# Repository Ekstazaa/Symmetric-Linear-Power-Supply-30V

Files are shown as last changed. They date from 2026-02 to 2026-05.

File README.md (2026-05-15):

# 🔌 Symetryczny zasilacz liniowy ±30 V

Projekt liniowego zasilacza symetrycznego przeznaczonego do zastosowań laboratoryjnych oraz testowania układów analogowych.

Układ umożliwia regulację napięcia dodatniego i ujemnego względem wspólnej masy oraz został zaprojektowany i zbudowany od podstaw – od schematu, przez PCB, aż po kompletną obudowę.

---

## 📷 Zdjęcia

### 🔧 Wnętrze


### 🎛️ Panel przedni


### 🔌 Tył


---

## ⚙️ Specyfikacja
\
| Parametr | Wartość |
|---|---|
| Napięcie wyjściowe | ±1.5 V do ±24 V (testowane) |
| Maksymalny prąd z jednej linii | ~1.5 A (regulatory) / ~4.5 A (z tranzystorami) |
| Transformator | toroidalny |
| Prąd transformatora | ~1.25 A |
| Topologia | liniowa |

---

## 🧠 Architektura

### Główne elementy:
- transformator toroidalny  
- mostek prostowniczy  
- kondensatory filtrujące  
- regulatory LM317 / LM337  
- tranzystory mocy (zwiększenie wydajności prądowej)  

---

## 🔌 Wyjścia

- 🔴 czerwony — +V  
- 🟢 zielony — GND  
- ⚫ czarny — -V  

---

## 🧪 Testy

Zasilacz został przetestowany przy użyciu prostych obciążeń (LED + rezystor).

Obserwacje:
- poprawna regulacja napięcia w całym zakresie  
- stabilna praca  
- brak zauważalnych problemów z regulacją  

---

## ⚠️ Problemy i kompromisy projektowe

### Inrush current

Największym problemem projektu okazał się prąd rozruchowy.

Duże kondensatory filtrujące na wejściu powodują:
- bardzo duży impuls prądu przy starcie  
- przepalanie bezpiecznika 1 A w gnieździe zasilania  

Tymczasowe rozwiązanie:
- zastosowanie bezpiecznika 4.5 A  

Nie jest to rozwiązanie docelowe, ponieważ:
- przekracza nominalny prąd transformatora (~1.25 A)  
- zmniejsza skuteczność zabezpieczenia  

Planowane rozwiązania:
- przeniesienie kondensatorów redukujących tętnienia z przed regulatorami do wyjścia regulatorów, które mają już konstrukcje softstartu.

---

### Ograniczenie prądu

- regulatory LM317 / LM337 posiadają ograniczenie prądowe (~1.5 A)  
- tranzystory mocy nie są zabezpieczone  

Planowane ulepszenie:
- zworka / bezpiecznik w torze tranzystorów  
- łatwiejsze debugowanie i zabezpieczenie układu  

### Kondensatory X i Y

- brakuje kondensatorów bezpieczeństaw X i Y

---

### Pomiar napięcia

Zastosowane analogowe mierniki:
- nie rozróżniają napięcia ujemnego  
- wskazują wartość bez uwzględnienia znaku  

---

### Mechanika i chłodzenie

- obudowa jest dość ciasna  
- ograniczony przepływ powietrza  
- potencjalne problemy termiczne przy dużym obciążeniu  

---

## 💬 Podsumowanie

Projekt jest w pełni działający i spełnia swoje założenia, jednak wymaga dalszego dopracowania w zakresie:

- zarządzania prądem rozruchowym  
- zabezpieczeń  
- warunków termicznych

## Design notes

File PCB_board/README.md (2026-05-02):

# Regulowany symetryczny zasilacz liniowy (Dual-Rail)

https://github.com/Ekstazaa/Symmetric-Linear-Power-Supply-30V/blob/main/PCB_board/README.md

---

## 📖 Opis

Ta płytka PCB implementuje transformatorowy, regulowany, symetryczny zasilacz liniowy oparty na układach LM317 (szyna dodatnia) oraz LM337 (szyna ujemna).  

Projekt jest przeznaczony do zastosowań laboratoryjnych oraz audio, gdzie wymagane jest regulowane napięcie symetryczne.

Zasilacz zawiera tranzystory mocy zwiększające wydajność prądową, zabezpieczenia wyjścia, dodatkową gałąź zasilania dla elektroniki panelowej oraz standardowe elementy stabilizujące zgodne z notami katalogowymi regulatorów.

---

### 🧊 Model 3D:


### 📐 Schemat:


---

## ⚡ Stopień wejściowy

Zasilacz jest zasilany z transformatora o parametrach:

- 2 × 32 VAC  
- Maksymalny prąd: 5 A na uzwojenie  

Prostowanie realizowane jest w konfiguracji dwudiodowej (pełnookresowej).

Po prostowaniu:

Każda szyna zawiera dwa kondensatory filtrujące 4700 µF (łącznie 9.4 mF na szynę).  
Ze względu na umiarkowaną pojemność filtrującą oraz możliwość pracy przy większych obciążeniach, tętnienia napięcia rosną przy wysokim poborze prądu.

---

## 🔧 Stopień regulacji

Regulacja napięcia realizowana jest przy użyciu:

- LM317 (szyna dodatnia)  
- LM337 (szyna ujemna)  

Regulatory są sterowane za pomocą zewnętrznych potencjometrów wieloobrotowych (montowanych na panelu przednim).

Dodatkowo na PCB przewidziano footprinty THT dla potencjometrów, co pozwala:
- używać regulacji bezpośrednio na płytce  
- skonfigurować układ jako źródło napięcia stałego  



Każdy regulator zawiera:

- kondensator wejściowy 100 nF  
- kondensator wyjściowy 1 µF  
- diody zabezpieczające przed rozładowaniem wstecznym  
- układ biasu startowego (kontrola zachowania przy starcie)

---

## 🔋 Stopień zwiększenia prądu

Aby zwiększyć wydajność prądową ponad ograniczenie ~1.5 A regulatorów LM317/LM337, zastosowano po jednym tranzystorze mocy (serii TIP) na każdą szynę.

Pozwala to na uzyskanie większego prądu wyjściowego, przy zachowaniu stabilizacji przez regulatory.

Zabezpieczenia wyjścia:

- bezpiecznik 4 A na każdą szynę  

Projekt zakłada maksymalny prąd ciągły na poziomie około 4 A.

---

## 📈 Maksymalne napięcie wyjściowe

Mimo zastosowania transformatora 2 × 30 VAC, maksymalne stabilizowane napięcie wyjściowe wynosi około:

±28 V DC  

Ograniczenie wynika ze spadków napięcia na:

- diodach prostownika  
- rezystancjach pasożytniczych  
- napięciu dropout regulatorów  
- spadku V_BE tranzystorów TIP  

---

## 🌡️ Warunki termiczne

Ze względu na wysokie napięcie wejściowe, przy niskim napięciu wyjściowym wydzielana jest znaczna moc strat.

Przybliżenie:

P ≈ (Vin - Vout) × Iout  

Ciepło wydziela się głównie w:

- regulatorach LM317 / LM337  
- tranzystorach mocy  

Zastosowane radiatory pozwalają na:

- LM317 / LM337: ~10 W  
- tranzystory TIP: ~17 W  

Zakłada to odpowiedni przepływ powietrza i poprawny montaż mechaniczny.  
Przy dużym prądzie i niskim napięciu wyjściowym może być wymagane dodatkowe chłodzenie.

---

## 🔌 Zasilanie pomocnicze

Dodatkowa gałąź oparta o LM7818 zapewnia:

- zasilanie mierników panelowych  
- diodę sygnalizacyjną LED  



---

## ⚠️ Uwagi projektowe i ograniczenia

Projekt został wykonany z użyciem transformatora 2 × 30 V, głównie ze względu na jego dostępność.  

W praktyce bardziej optymalny byłby transformator o niższym napięciu wtórnym (np. 2 × 16–18 V).

W obecnym zastosowaniu wymagane napięcie to maksymalnie ±12 V, co oznacza, że:

- transformator jest przewymiarowany napięciowo  
- występują duże spadki napięcia na regulatorach  
- generowane są znaczne straty mocy  

W przyszłości planowana jest zmiana transformatora na lepiej dopasowany do zastosowania.  
Obecnie testy wykonywane są bez dużych obciążeń.

Dodatkowo:

- PCB umożliwia montaż potencjometrów THT  
- dostępne są dwa terminale śrubowe na każdą szynę (większa wygoda i elastyczność)

---

## 📁 Opis plików projektu

- **Power_supply.kicad_sch**  
  Schemat elektryczny w KiCad

- **Power_supply.kicad_pcb**  
  Layout PCB (rozmieszczenie elementów i ścieżki)

- **Power_supply.kicad_pro**  
  Plik projektu KiCad

- **Power_supply.zip**  
  Pliki produkcyjne (Gerbery + wiercenia)

- **bom.csv**  
  Lista elementów (Bill of Materials)

- **positions.csv**  
  Plik pick-and-place (pozycje komponentów)

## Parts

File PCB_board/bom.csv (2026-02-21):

Designator | Footprint | Quantity | Value | LCSC Part #
C1, C2, C3, C4 | HE1J478M30040HA | 4 | 4m7
C10, C9 | C_Radial_D5.0mm_H7.0mm_P2.00mm | 2 | 10u
C11, C12, C5, C6 | 0805 | 4 | 100n
C7, C8 | 0805 | 2 | 1u
D1, D2, D3, D4, D5, D6 | D_DO-201AD_P15.24mm_Horizontal | 6 | 1N5408
D7, D8 | D_SOD-523 | 2 | 1N4148WT
H2, H3 | PTF15 | 2 | Fuse4A
IC1 | TO255P460X1020X2008-3P | 1 | LM317T
IC2 | TO255P460X1020X2008-3P | 1 | LM337SP
J1 | DG3015003P1200AH | 1 | DG301-5.0-03P-12-00A_H_
J2 | 2828366 | 1 | 282836-6
J3 | PinSocket_2x06_P2.54mm_Vertical | 1 | Conn_02x06_Counter_Clockwise
Q1 | TO545P515X1560X2445-3P | 1 | TIP2955
Q2 | TO545P515X1560X2445-3P | 1 | TIP3055
Q3 | SOT-23 | 1 | BC807
Q4 | SOT-23 | 1 | BC817
R1, R3 | 0603 | 2 | 240
R2, R4 | 0603 | 2 | 50k
R5, R8 | R_Axial_DIN0516_L15.5mm_D5.0mm_P20.32mm_Horizontal | 2 | 0.1
R6, R7 | R_Axial_DIN0516_L15.5mm_D5.0mm_P20.32mm_Horizontal | 2 | 1
R9 | 0603 | 1 | 2k
RV+1, RV-1 | Potentiometer_ACP_CA9-H5_Horizontal | 2 | R_Potentiometer
U1 | TO-220-3_Vertical | 1 | LM7818_TO220
U2, U3, U4, U5 | FAT22025E | 4 | FA-T220-25E

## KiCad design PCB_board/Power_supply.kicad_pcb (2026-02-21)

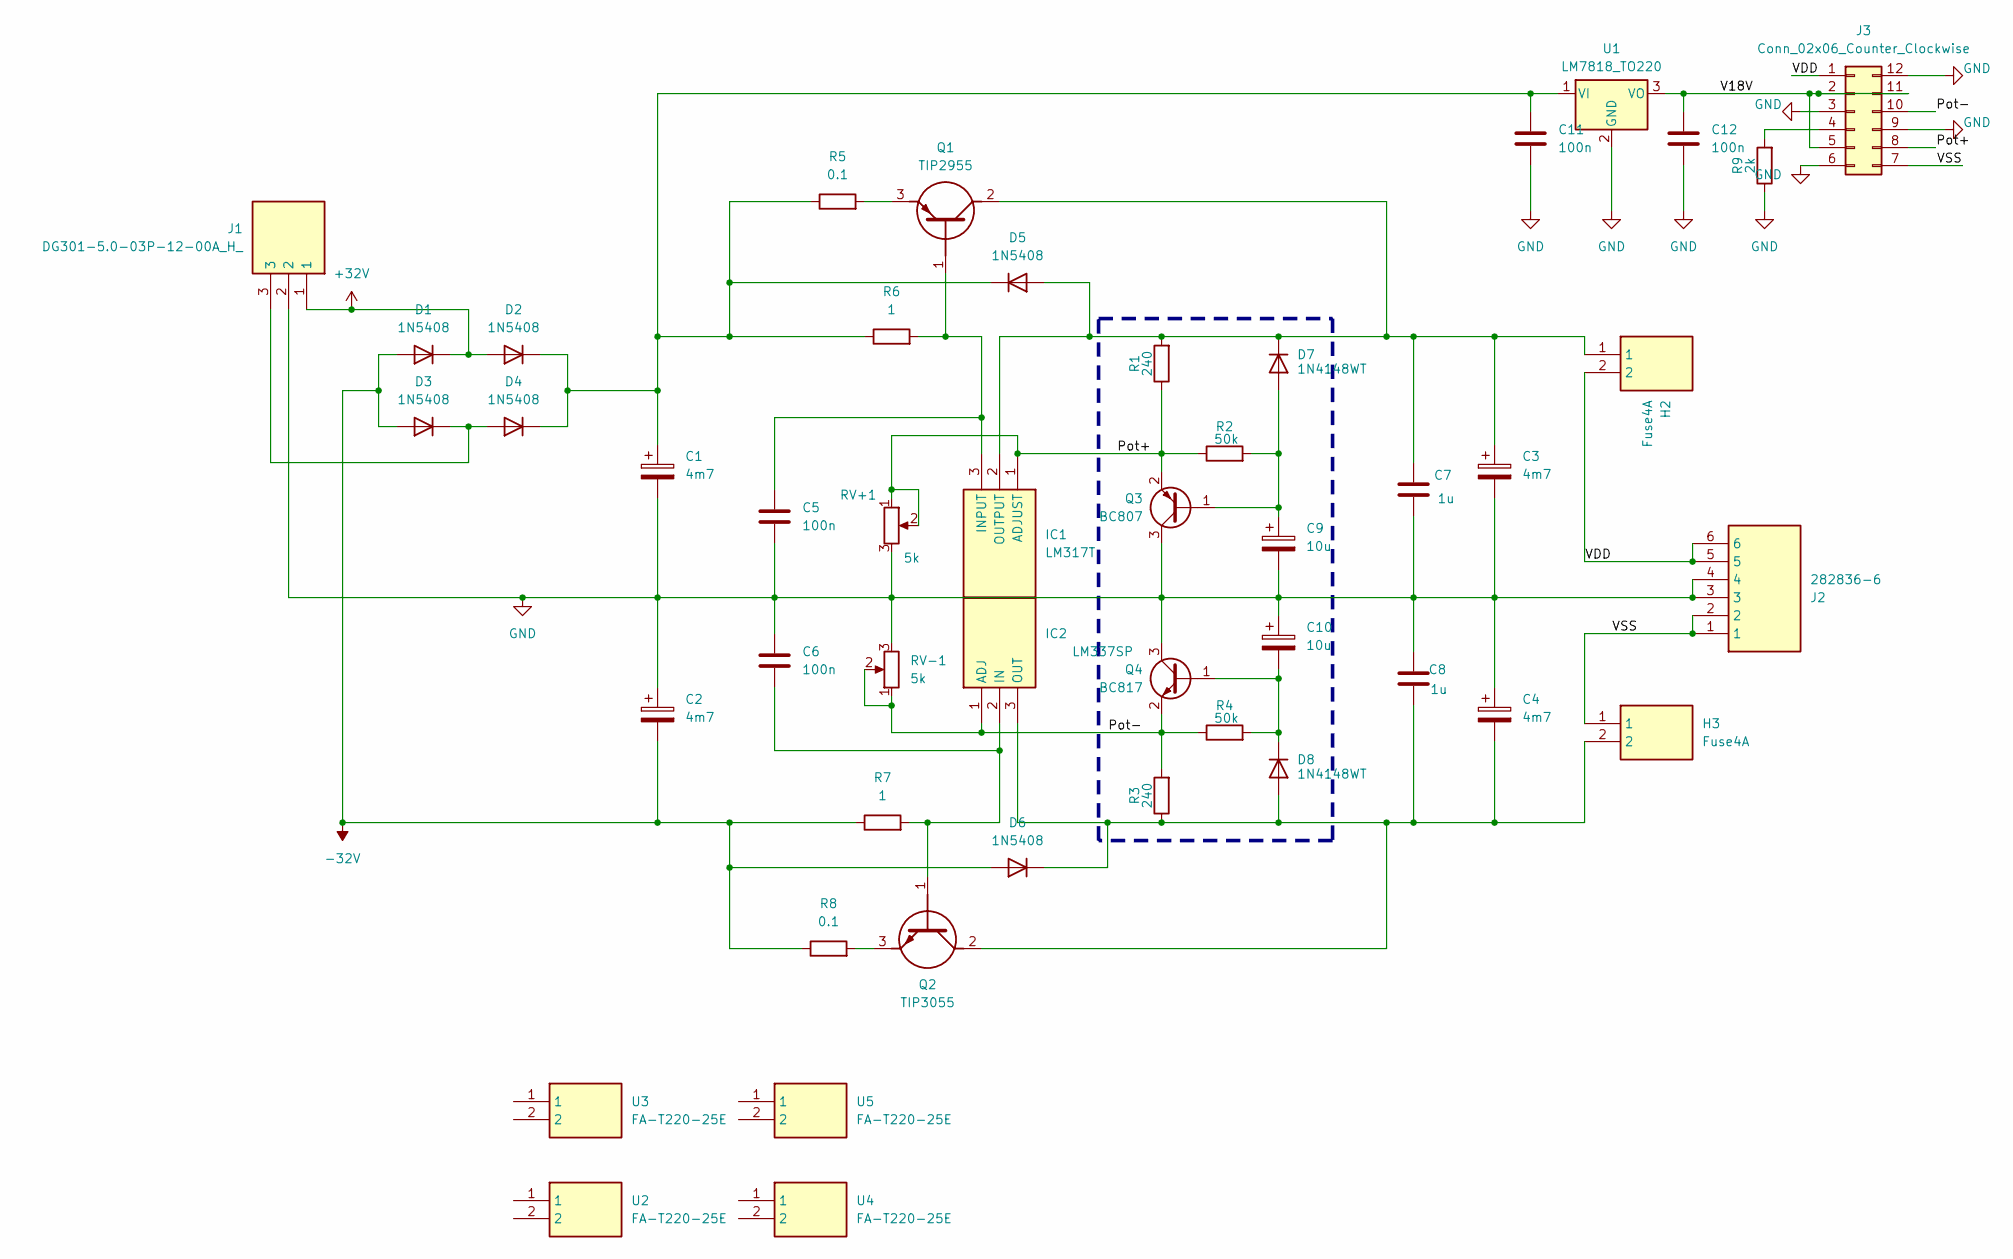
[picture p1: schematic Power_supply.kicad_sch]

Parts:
C1, C2, C3, C4: 4m7; HE1J478M30040HA
C5, C6, C11, C12: 100n; C_0805_2012Metric
C7, C8: 1u; C_0805_2012Metric
C9, C10: 10u; C_Radial_D5.0mm_H7.0mm_P2.00mm
D1, D2, D3, D4, D5, D6: 1N5408; D_DO-201AD_P15.24mm_Horizontal
D7, D8: 1N4148WT; D_SOD-523
H2, H3: Fuse4A; PTF15; Manufacturer_Part_Number PTF/15
IC1: LM317T; TO255P460X1020X2008-3P; Manufacturer_Part_Number LM317T
IC2: LM337SP; TO255P460X1020X2008-3P; Manufacturer_Part_Number LM337SP
J1: DG301-5.0-03P-12-00A_H_; DG3015003P1200AH; Manufacturer_Part_Number DG301-5.0-03P-12-00A(H)
J2: 282836-6; 2828366; Manufacturer_Part_Number 282836-6
J3: Conn_02x06_Counter_Clockwise; PinSocket_2x06_P2.54mm_Vertical
Q1: TIP2955; TO545P515X1560X2445-3P; Manufacturer_Part_Number TIP2955
Q2: TIP3055; TO545P515X1560X2445-3P; Manufacturer_Part_Number TIP3055
Q3: BC807; SOT-23
Q4: BC817; SOT-23
R1, R3: 240; R_0603_1608Metric_Pad0.98x0.95mm_HandSolder
R2, R4: 50k; R_0603_1608Metric_Pad0.98x0.95mm_HandSolder
R5, R8: 0.1; R_Axial_DIN0516_L15.5mm_D5.0mm_P20.32mm_Horizontal
R6, R7: 1; R_Axial_DIN0516_L15.5mm_D5.0mm_P20.32mm_Horizontal
R9: 2k; R_0603_1608Metric_Pad0.98x0.95mm_HandSolder
RV+1: 5k; Potentiometer_ACP_CA9-H5_Horizontal
RV-1: 5k; Potentiometer_ACP_CA9-H5_Horizontal
U1: LM7818_TO220; TO-220-3_Vertical
U2, U3, U4, U5: FA-T220-25E; FAT22025E; Manufacturer_Part_Number FA-T220-25E

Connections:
+32V: D1.1 (K), D2.2 (A), J1.1
-32V: C2.2, D1.2 (A), D3.2 (A), D6.2 (A), R7.1, R8.1
/Pot+: IC1.1 (ADJUST), J3.8, Q3.2 (E), R1.1, R2.1, RV+1.1, RV+1.2
/Pot-: IC2.1 (ADJ), J3.10, Q4.2 (E), R3.2, R4.1, RV-1.1, RV-1.2
/V18V: C12.1, J3.2, J3.5, J3.11, U1.3 (VO)
/VDD: H2.2, J2.5, J2.6, J3.1
/VSS: H3.1, J2.1, J2.2, J3.7
GND: C1.2, C2.1, C3.2, C4.1, C5.2, C6.1, C7.2, C8.1, C9.2, C10.1, C11.2, C12.2, J1.2, J2.3, J2.4, J3.3, J3.6, J3.9, J3.12, Q3.3 (C), Q4.3 (C), R9.1, RV+1.3, RV-1.3, U1.2 (GND)
unnamed: C1.1, C11.1, D2.1 (K), D4.1 (K), D5.1 (K), R5.1, R6.1, U1.1 (VI)
unnamed: D3.1 (K), D4.2 (A), J1.3
unnamed: C3.1, C7.1, D5.2 (A), D7.1 (K), H2.1, IC1.2 (OUTPUT), Q1.2 (C), R1.2
unnamed: C4.2, C8.2, D6.1 (K), D8.2 (A), H3.2, IC2.3 (OUT), Q2.2 (C), R3.1
unnamed: C9.1, D7.2 (A), Q3.1 (B), R2.2
unnamed: C10.2, D8.1 (K), Q4.1 (B), R4.2
unnamed: C5.1, IC1.3 (INPUT), Q1.1 (B), R6.2
unnamed: C6.2, IC2.2 (IN), Q2.1 (B), R7.2
unnamed: J3.4, R9.2
unnamed: Q1.3 (E), R5.2
unnamed: Q2.3 (E), R8.2

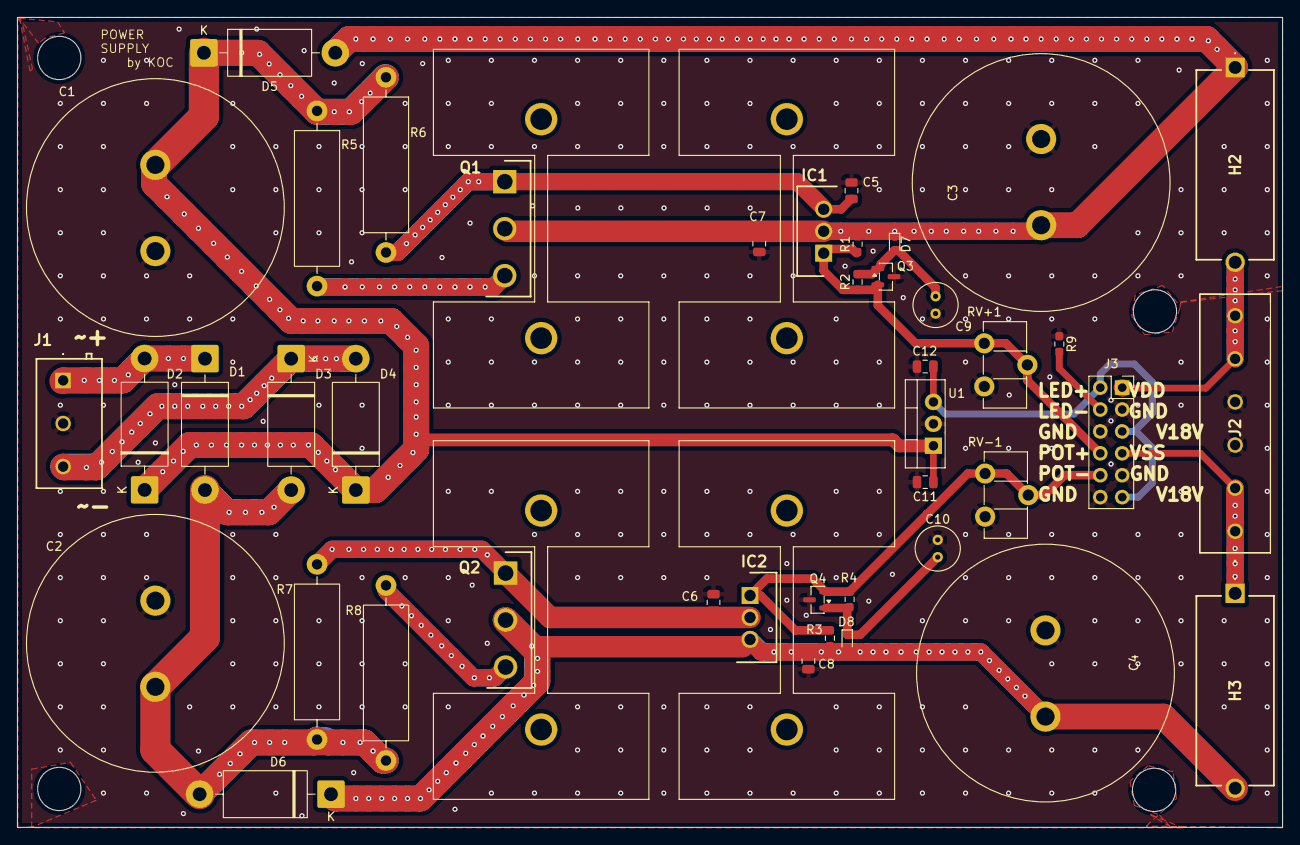
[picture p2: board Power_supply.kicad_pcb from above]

Board: 2 copper layers, 146.8 x 93.9 mm, 47 parts (0 on the bottom side), 19 nets.
